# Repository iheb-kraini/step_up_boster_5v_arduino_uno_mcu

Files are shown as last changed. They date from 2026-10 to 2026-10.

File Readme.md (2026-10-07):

Digitally Regulated Boost Converter (Arduino Uno PID)

A closed-loop DC-DC Step-Up (Boost) Converter driven by an Arduino Uno R3. The system continuously samples output voltage through a $10\text{ k}\Omega + 10\text{ k}\Omega$ feedback divider, processes the reading through an Exponential Moving Average (EMA) filter, executes a $1\text{ kHz}$ discrete PID loop with anti-windup, and updates a custom $10\text{ kHz}$ Fast PWM signal on Timer 1.
---

## Features

* **Firmware:** Written for Arduino Uno R3 (ATmega328P).
* **Simulation:** Full circuit simulation in Proteus.
* **Hardware:** Custom PCB designed in KiCad.
* **Power Supply:** Input range `3V–4.2V DC` via terminal block.

---

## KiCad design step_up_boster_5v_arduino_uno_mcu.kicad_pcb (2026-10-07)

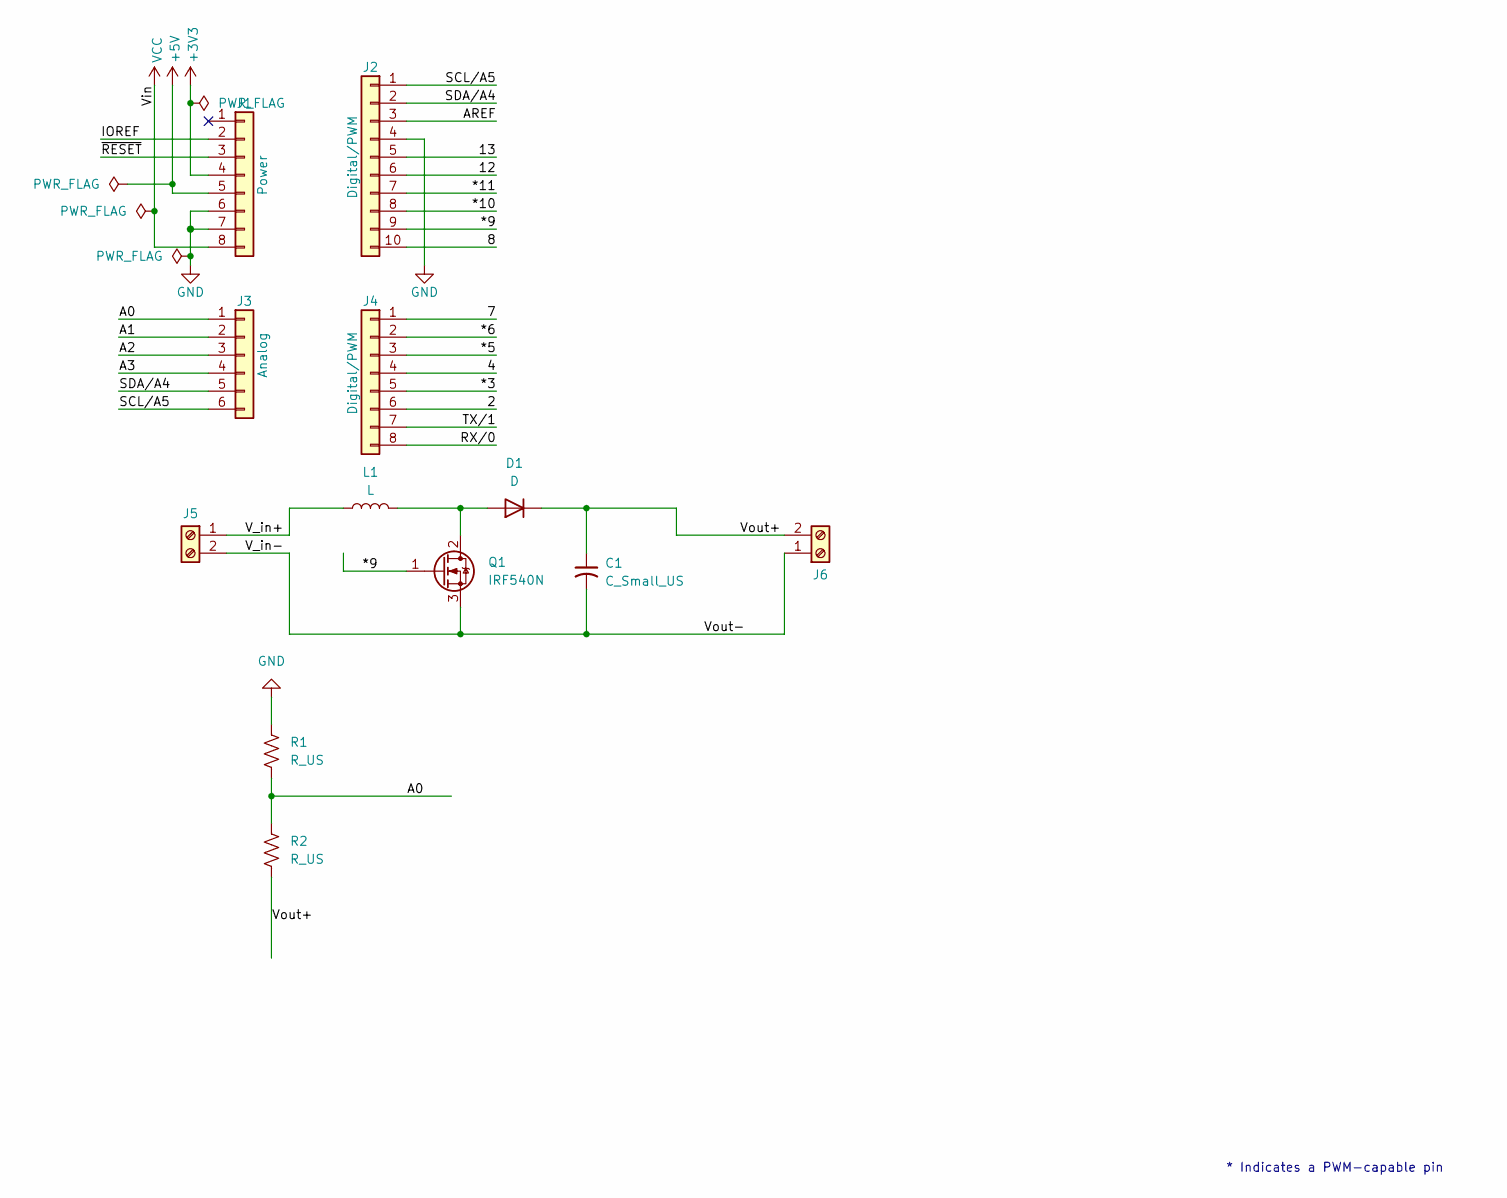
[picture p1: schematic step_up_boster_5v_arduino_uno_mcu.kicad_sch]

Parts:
C1: C_Small_US; CP_Radial_D10.0mm_P2.50mm
D1: D; D_DO-41_SOD81_P10.16mm_Horizontal
J1: Power; PinSocket_1x08_P2.54mm_Vertical
J2: Digital/PWM; PinSocket_1x10_P2.54mm_Vertical
J3: Analog; PinSocket_1x06_P2.54mm_Vertical
J4: Digital/PWM; PinSocket_1x08_P2.54mm_Vertical
J5, J6: Screw_Terminal_01x02; TerminalBlock_Phoenix_MKDS-1,5-2-5.08_1x02_P5.08mm_Horizont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
L1: L; L_Axial_L16.0mm_D9.5mm_P20.32mm_Horizontal_Vishay_IM-10-37
Q1: IRF540N; TO-220-3_Vertical
R1, R2: R_US; R_Axial_DIN0309_L9.0mm_D3.2mm_P12.70mm_Horizontal

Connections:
+3V3: J1.4
+5V: J1.5
/2: J4.6
/4: J4.4
/7: J4.1
/8: J2.10
/12: J2.6
/13: J2.5
/*3: J4.5
/*5: J4.3
/*6: J4.2
/*9: J2.9, Q1.1 (G)
/*10: J2.8
/*11: J2.7
/A0: J3.1, R1.2, R2.1
/A1: J3.2
/A2: J3.3
/A3: J3.4
/AREF: J2.3
/IOREF: J1.2
/RX/0: J4.8
/SCL/A5: J2.1, J3.6
/SDA/A4: J2.2, J3.5
/TX/1: J4.7
/V_in+: J5.1, L1.1
/V_in-: C1.2, J5.2, J6.1, Q1.3 (S)
/Vout+: C1.1, D1.1 (K), J6.2, R2.2
/~RESET: J1.3
GND: J1.6, J1.7, J2.4, R1.1
unnamed: D1.2 (A), L1.2, Q1.2 (D)
VCC: J1.8

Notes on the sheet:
* Indicates a PWM-capable pin

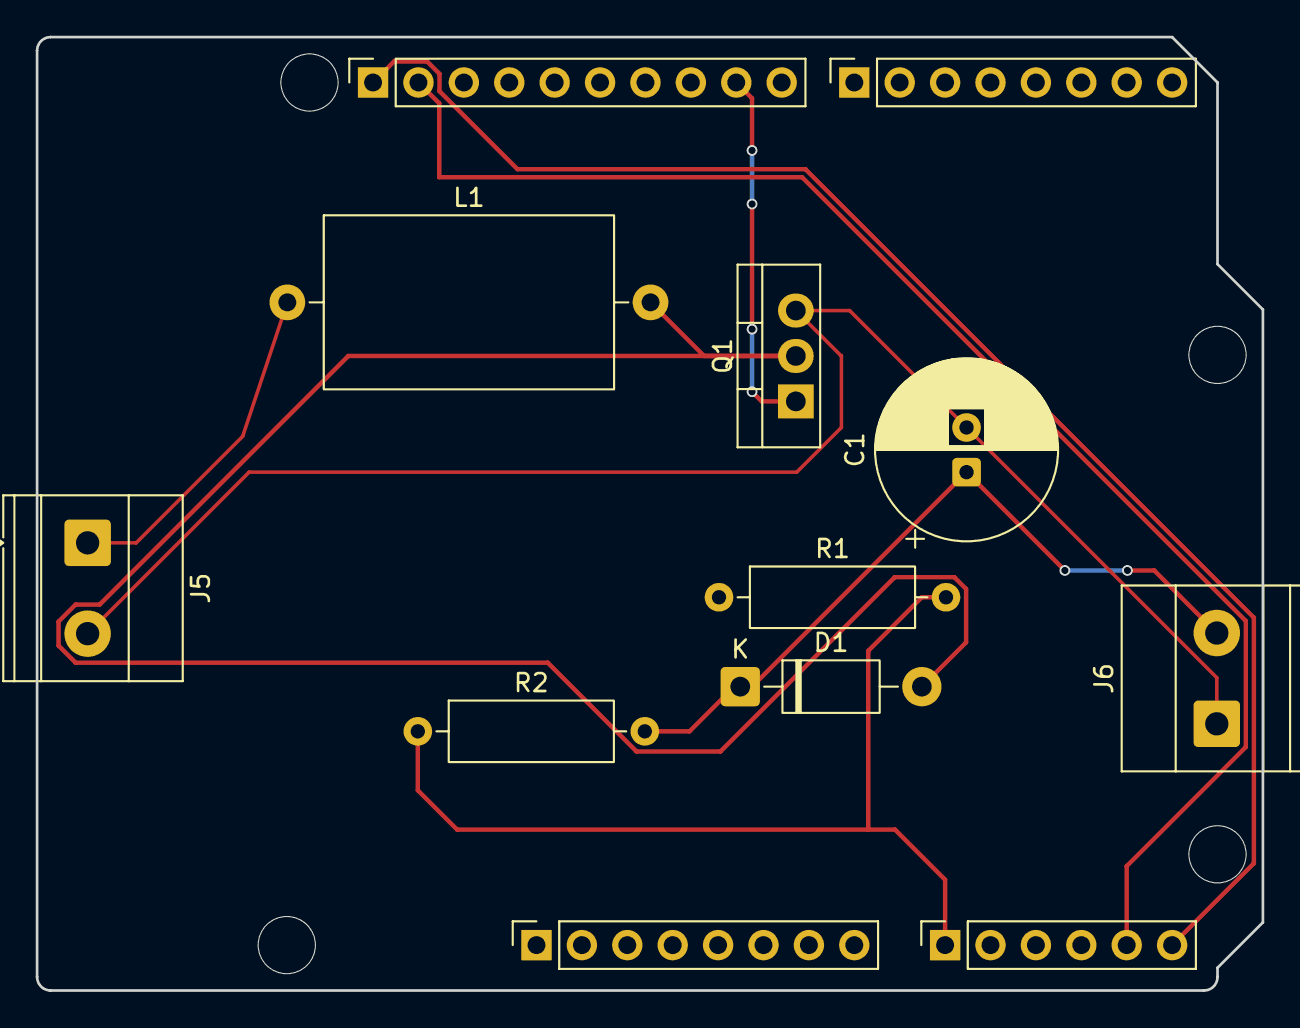
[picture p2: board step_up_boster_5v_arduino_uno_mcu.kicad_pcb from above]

Board: 2 copper layers, 68.6 x 53.3 mm, 16 parts (0 on the bottom side), 9 nets.

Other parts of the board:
MH1, MH2, MH3, MH4: MountingHole_3.2mm

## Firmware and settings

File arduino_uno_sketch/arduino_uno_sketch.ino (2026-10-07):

#include <Arduino.h>

const uint8_t FB_PIN  = A0;
const uint8_t PWM_PIN = 9;

const uint16_t PWM_TOP = 1599;
const uint16_t PWM_MIN = 80;     // ~5%
const uint16_t PWM_MAX = 1439;   // ~90%

const float DIV_RATIO = 2.0;     // 10k + 10k divider
const float DUTY_FF   = 150;   //12% //640.0;   // ~40% feedforward

// Stable PID gains for 1 kHz loop
float Kp = 20;                 
float Ki = 5000.0;                
float Kd = 0.0;                 // D-term damps oscillation/overshoot

float target_voltage = 5.0;
float integral = 0.0;
float prev_error = 0.0;
float v_fb_filtered = 0.0;
float output_pwm = DUTY_FF;

unsigned long last_time = 0;
const unsigned int sample_interval_us = 1000; // 1 kHz

void setup() {
  pinMode(PWM_PIN, OUTPUT);

  TCCR1A = 0;
  TCCR1B = 0;
  TCNT1  = 0;
  TCCR1A |= (1 << COM1A1) | (1 << WGM11);
  TCCR1B |= (1 << WGM13) | (1 << WGM12) | (1 << CS10);
  ICR1  = PWM_TOP;
  OCR1A = (uint16_t)DUTY_FF;

  ADCSRA = (ADCSRA & 0xF8) | 0x04; // Prescaler 16 (~105 us per ADC read)
  last_time = micros();
}

void loop() {
  unsigned long now = micros();
  if (now - last_time < sample_interval_us) return;

  float dt = (now - last_time) / 1000000.0;
  last_time = now;

  // Single fast read + Exponential Moving Average filter (70% old, 30% new)
  float raw_v = (analogRead(FB_PIN) * 5.0 / 1023.0) * DIV_RATIO;
  v_fb_filtered = (0.7 * v_fb_filtered) + (0.3 * raw_v);

  float error = target_voltage - v_fb_filtered;

  // Integral accumulation with anti-windup clamp
  float next_integral = integral + error * dt;
  next_integral = constrain(next_integral, -1.5, 1.5);

  // Derivative calculation for damping
  float derivative = (error - prev_error) / dt;
  prev_error = error;

  // PID Output
  output_pwm = DUTY_FF + (Kp * error) + (Ki * next_integral) + (Kd * derivative);

  // Update integral only if output is not saturated (Anti-Windup)
  if (output_pwm >= PWM_MIN && output_pwm <= PWM_MAX) {
    integral = next_integral;
  }

  output_pwm = constrain(output_pwm, PWM_MIN, PWM_MAX);
  OCR1A = (uint16_t)output_pwm;
}
